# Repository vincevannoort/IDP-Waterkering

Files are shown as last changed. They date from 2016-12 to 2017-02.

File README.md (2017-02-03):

# IDP-Waterkering
De applicatie voor de IDP Waterkering levert een Proof of Concept voor een waterkering op schaal. De waterkering meet door middel van een ultrasonische sensor de waterstand. Indien het water te hoog staat worden waterkeringdeuren gesloten door stappenmotoren. Wanneer het water daarna weer op normaal niveau is, worden de waterkeringdeuren weer geopend. Door een failover systeem wordt gegarandeerd dat de waterkering altijd zal werken.

## Benodigdheden (hardware)
- HC-SR04 ultrasonische sensor - 1x
- 28byj-48 stappenmotor - 2x
- Raspberry Pi - 2x
- Jumper Wires (MM, MF, FF)
- Resistors (330ohm & 470ohm)
- Breadboard
- UTP netwerkkabel

## Installatie (software op beide Raspberry Pi's)
1. **Configureer Raspberry Pi's**  
   Formateer beide SD-cards via Win32DiskImager. Installeer Raspbian met behulp van een iso bestand. Verdere instructies te lezen op: [Raspbian install](https://www.raspberrypi.org/documentation/installation/installing-images/)
   
2. **Configureer verbinding Raspberry Pi's met sensoren en motoren**  
   Om de Raspberry Pi's met de sensors en motoren te verbinden in een schema gemaakt in Fritzing. Met de benodigdheden kun je de sensors en motoren aan het breadboard koppelen en het breadboard aan de twee Raspberry Pi's. [Fritzing instructie](http://i.imgur.com/pFn06OUg.png)

3. **Configureer netwerk**  
   Om de Raspberry Pi's met elkaar verbinding te kunnen laten maken, moet ervoor worden gezorgt dat de Raspberry Pi's een statisch IP hebben. Hiervoor moeten op beide Raspberry Pi's het netwerk interface bestand worden aangepast.  

   Raspberry Pi 1
   ```
   sudo nano /etc/network/interfaces
   ```
   ```
   auto eth0
   iface eth0 inet static
   address 192.137.0.1
   netmask 255.255.255.0
   ```
   Sla op met `ctrl+o`, `enter` gevolgd door `ctrl+x`  

   Raspberry Pi 2
   ```
   sudo nano /etc/network/interfaces
   ```
   ```
   auto eth0
   iface eth0 inet static
   address 192.137.0.2
   netmask 255.255.255.0
   ```
   Sla op met `ctrl+o`, `enter` gevolgd door `ctrl+x`
   Hierna kun je de verbinding testen door op Raspberry Pi 1 te pingen door ```ping 192.168.137.2``` in te voeren en vanaf Raspberry Pi 2 te pingen door ```ping 192.168.137.1``` in te voeren.

4. **Configureer SSH op beide Raspberry Pi's**  
   Om de applicatie verbinding te laten maken met de Raspberry Pi's wordt een SSH verbinding gebruikt. Deze moet op beide Raspberry Pi's worden ingesteld. Voer op beide Raspberry Pi's het onderstaande commando in.
   ```
   sudo ssh-keygen
   ```
   ```
   sudo raspi-config
   ```  
   Raspberry Pi 1
   ```
   ssh-copy-id -i ~/.ssh/id_rsa.pub 192.137.0.2
   ```  
   Raspberry Pi 2
   ```
   ssh-copy-id -i ~/.ssh/id_rsa.pub 192.137.0.1
   ```  
   Hierna kun je de verbinding testen door op Raspberry Pi 1 het commando ```ssh 192.137.0.2``` in te voeren en vanaf Raspberry Pi 2 het commando ```ssh 192.137.0.1``` in te voeren.

5. **Installeer Django en Django Channels**  
   Raspbian komt geisntalleerd met Python3 en de package manager pip. Door middel van pip kun je de juiste packages installeren die ervoor zorgen dat de webserver kan draaien.
   ```
   sudo pip3 install Django
   ```
   ```
   sudo pip3 install -U channels
   ```

6. **Download applicatie naar beide Raspberry Pi's**  
   Om alle bestanden op de Raspberry Pi's te krijgen, kan de repository met git worden gekopieerd.
   ```
   git clone 'https://github.com/vincevannoort/IDP-Waterkering.git'
   ```

7. **Applicatie starten op beide Raspberry Pi's**  
   Op beide Raspberry Pi's moet de applicatie draaien. Op de eerste moet de Django server draaien, en op de tweede het failover script.  

   Raspberry Pi 1
   ```
   cd IDP-Waterkering/applicatie
   ```
   ```
   sudo python3 manage.py runserver
   ```  

   Raspberry Pi 2
   ```
   cd IDP-Waterkering/redudantie
   ```
   ```
   sudo python3 rpi2-check-last-db-update.py
   ```

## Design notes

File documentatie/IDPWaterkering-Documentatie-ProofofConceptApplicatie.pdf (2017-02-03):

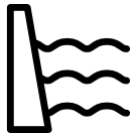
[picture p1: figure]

# Documentatie -Proof of Concept & Applicatie

IDP Waterkering

Gemaakt door:
Bart Hiemstra
Sijmen Jaarsma
Vince van Noort

IDP project 2016 - Sijmens Angels | Team 4 - V1B

### Inhoudsopgave

Documentatie -
Proof of Concept & Applicatie | 1
Inhoudsopgave | 2
Proof of Concept | 3
Functioneel Ontwerp | 4
Technisch Ontwerp | 6
Sensor | 6
Motoren | 6
Applicatie | 6
Websockets | 7
Programmeertaal | 7
Threads | 7
Failover | 7
Fritzing model | 8
Algemene werking | 9
Motor thread | 9
Sensor thread | 10
Testen van het systeem | 11
Doel | 11
Meten of de ultrasone sensor correct werkt | 11
Controleren of de poort opent/sluit op basis van de waterstand | 11
Testen of het failover systeem correct werkt | 12
Testen van de werking van de motoren | 12
Bronvermelding | 12

# Proof of Concept

Het Proof of Concept van de waterkering meet door middel van een ultrasonische sensor de waterstand. Indien het water te hoog staat worden sluisdeuren gesloten. Wanneer het water daarna weer op normaal niveau is, worden de sluisdeuren weer geopend. Door een failover systeem wordt gegarandeerd dat de waterkering altijd zal werken.

In het Proof of Concept zijn de onderstaande onderdelen gebruikt:

Hardware:
- HC-SR04 ultrasonische sensor - 1x
- 28byj-48 stappenmotor - 2x
- Raspberry Pi - 2x
- Jumper Wires (MM, MF, FF)
- Resistors (330ohm & 470ohm)
- Breadboard
- UTP netwerkkabel

Software:
- Django
- Django Channels
- Vue.js & Chart.js

### Functioneel Ontwerp

In het Plan van Aanpak is er beschreven wat de applicatie moet kunnen. De beschrijving die wij hebben gegeven luidt:

“Aan het einde van het project, op 3 februari 2017, wil ons team een prototype opleveren dat de maeslantkering nabootst. Dit prototype moet kunnen meten hoe hoog het water staat, de gemeten data opslaan en reageren op de stand van het water. De documentatie die wordt geschreven bij het prototype is duidelijk voor een student HBO-ICT eerstejaars aan de Hogeschool Utrecht. Het schaalmodel zal op zijn minst sensoren voor het meten van de waterstand bevatten, met daarnaast een sluisdeur die bediend wordt door twee stappenmotoren. Indien haalbaar willen we dit systeem werkzaam maken in een bak met water. Aan het einde van het project zullen wij een posterpresentatie houden die voldoet aan de eisen van het iPass project.”

Wat moet de het proof of concept concreet kunnen?

1. De applicatie moet kunnen draaien op een Raspberry Pi 3 Model B+
De Raspberry Pi 3 Model B+ is een minicomputer, ontworpen om applicaties te draaien. Ons team wil graag een Python programma laten draaien op zo’n minicomputer. Hiervoor moeten we rekening houden met wat de Raspberry Pi qua computerkracht aankan.
2. De waterstand moet per seconde kunnen worden gemeten door een ultrasonische sensor
De Raspberry Pi moet een ultrasonische sensor kunnen aansturen om de waterstand te meten. Een ultrasonische sensor is een sensor die een geluidsgolf afschiet met een erg hoge frequentie (onhoorbaar voor mensen). Deze geluidsgolf weerkaatst op een object. De tijd die de geluidsgolf erover doet om terug te komen naar de sensor, kan worden omgerekend naar een afstand op basis van de snelheid van geluid (343 meter per seconde).
3. De waterstanden moeten worden opgeslagen in een SQLite database
De gemeten afstand moet kunnen worden opgeslagen. Dit willen wij bereiken door dit in een SQLite database te doen. Een SQLite database is een enkel bestand die fungeert als database. In deze database kun je makkelijk data ophalen en opslaan.
4. De twee motoren moeten op basis van de gemeten waterstand worden aangestuurd
De motoren moeten worden aangestuurd door de applicatie op basis van de laatste paar metingen. Wanneer de gemeten waterstand over een langere tijd een ingestelde grens overschrijdt, zal de applicatie de motoren moeten aansturen om open of dicht te gaan.

### 5. De twee motoren moeten deuren kunnen dragen en een nauwkeurige aantal

graden kunnen draaien
De door de Raspberry Pi gestuurde motoren moeten een nauwkeurig aantal graden kunnen draaien terwijl deze de deuren van de waterkering draagt. Het aantal nauwkeurige graden moet kunnen worden beheerd in de applicatie.
6. Meldingen van het aansturen van de deuren moeten worden opgeslagen in een database
De meldingen die worden gegeven door de applicatie wanneer de deuren worden aangestuurd, moeten kunnen worden opgeslagen in een database (hiervoor benoemd).
7. De gemeten waterstanden en meldingen moeten in een webapplicatie worden getoond, hierin moet je een grafiek kunnen zien waarin je de waterstand van afgelopen minuut kunt bekijken
De waterstanden moeten worden weergegeven in een grafiek via de webapplicatie. Een webapplicatie is een applicatie die je via een browser kunt bekijken en hiermee interacteren. De grafiek biedt de optie om de geschiedenis van de waterstand te kunnen zien.
8. De sensoren en motoren moeten kunnen worden aangestuurd door een Raspberry Pi en indien deze uitvalt door een backup Raspberry Pi (ook wel Failover genoemd)
De waterkering moet met een failover systeem kunnen draaien. Dat betekent dat wanneer de Raspberry Pi (die de sensoren en motoren aanstuurt) uitvalt, een andere Raspberry Pi dit kan overnemen. Dit zorgt ervoor dat wanneer er geen stroom meer is of de applicatie crasht, het proces niet komt stil te staan.

### Technisch Ontwerp

In de onderstaande afbeelding is een representatie van het technisch ontwerp te zien, waarin de vereiste onderdelen zijn verwerkt. Hierin zijn de sluisdeuren weggelaten om alleen op het technisch gedeelte in te gaan.

### Sensor

De HC-SR04 ultrasonische sensor wordt gebruikt in het PoC. Er is voor deze sensor gekozen omdat het een goedkope maar zeer nauwkeurige sensor is. De sensor werkt op basis van geluid, zoals de naam al omschrijft. De sensor
kan op een afstand van 2 - 500 cm op 0.3cm nauwkeurig
meten, na deze afstand werkt de sensor niet meer naar
behoren. De sensor zal de afstand meten door de ultrasonische golf op het water te weerkaatsen en deze terug te ontvangen in de sensor. De sensor heeft vier pinnen waaronder: stroom, trigger, echo en aarde. Op bladzijde [BLADZIJDE] is gedocumenteerd hoe de ultrasonische sensor in het PoC is verwerkt.

Verantwoording: nauwkeurig en goedkoop

### Motoren

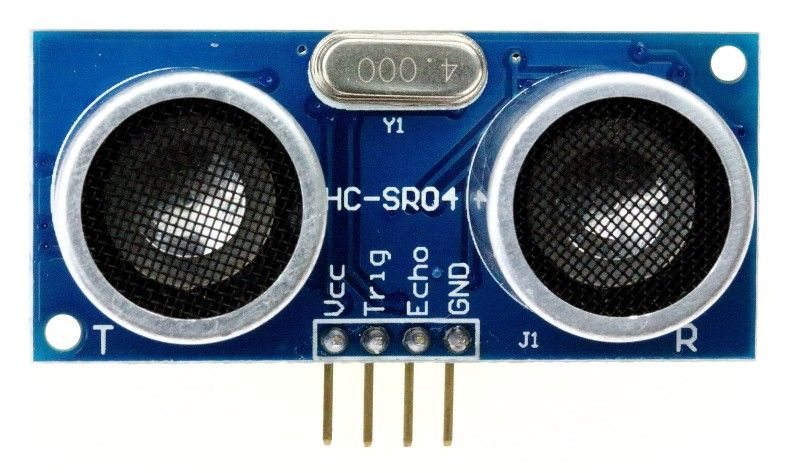
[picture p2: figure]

De 28byj-48 stappenmotor wordt gebruikt om de sluisdeuren aan te sturen. Deze stappenmotoren zijn gekozen omdat je ze aan kunt sturen
in een aantal graden en omdat ze heel goedkoop
beschikbaar zijn. Wanneer je een 28byj-48 stappenmotor
online bestelt, krijg je een motordriver bord erbij. De motoren werken door het aanzetten van verschillende magnetische velden. Door dit snel achter elkaar te doen gaat de motor draaien. Op bladzijde [BLADZIJDE] is gedocumenteerd hoe de stappenmotoren in het PoC zijn verwerkt.

Verantwoording: aantal graden aanstuurbaar en goedkoop

### Applicatie

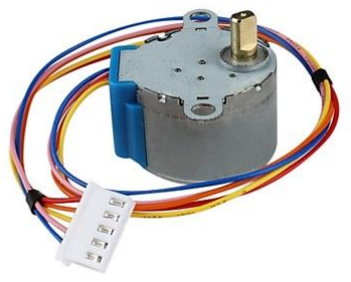
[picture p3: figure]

Om de applicatie is gekozen voor het Python Framework Django. De keuze voor Django is gebaseerd op dat Django betrouwbaar is en het toelaat om een applicatie snel te programmeren. Pinterest & Disqus zijn goede voorbeelden voor de betrouwbaarheid van Django, applicaties die dagelijks door
miljoenen mensen worden gebruikt.

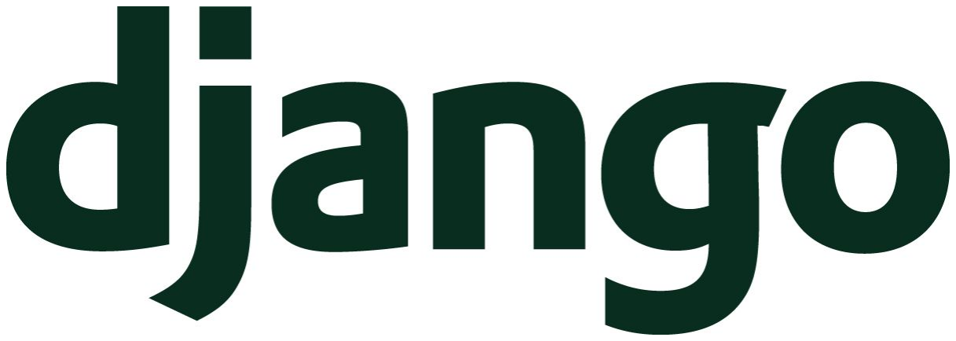
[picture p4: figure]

Verantwoording: betrouwbaar

### Websockets

Om vanaf meerdere browsers de webapplicatie synchroon te kunnen bekijken hebben we gekozen voor Django Channels. Een implementatie van websockets in Django. De websockets zorgen ervoor dat elke openstaande browser dezelfde updates door krijgt van de server. Zo zouden er meerdere schermen in een gebouw kunnen staan die de waterstanden door krijgen.

Verantwoording: synchroon monitoring en dichte integratie met Django

### Programmeertaal

Om de applicatie te programmeren hebben we samen met het framework Django gekozen voor Python. We hebben deze keuze gemaakt omdat Django is gebouwd op Python en om deze reden is de applicatie relatief erg snel in elkaar te zetten. Python is een programmeertaal die makkelijk te begrijpen is maar weinig grenzen heeft naast snelheid vergeleken met talen als C/C# en Java.

Verantwoording: prototype snel op te stellen

### Threads

We hebben er voor gekozen om met threads te werken voor de Applicatie. De reden hiervoor is dat we kunnen garanderen dat een lopende functie de andere functie niet blokkeert. In de applicatie zijn er naast de standaard Django threads, 2 threads die constant zichzelf herhalen. De implementatie van deze threads staat verderop in dit document beschreven.

Verantwoording: parallelle processen

### Failover

Voor de failover hebben we gekozen om twee Raspberry Pi’s met een ethernet kabel met elkaar te verbinden. De verbinding gaat via een veilige SSH verbinding met encryptie. Er zijn 2 verschillende type Raspberry Pi’s. De hoofd Raspberry Pi, en de failover Raspberry Pi. De hoofd Raspberry Pi kopieert elke 20 seconden de geupdate SQLite database file naar de Failover Raspberry Pi. De failover Raspberry Pi controleert elke 20 seconden of het databasebestand (dat vanaf de hoofd Raspberry Pi gekopieerd zou moeten zijn), niet ouder is dan 60 seconden. Indien het de hoofd Raspberry Pi, 3 keer niet is gelukt om het databasebestand te kopiëren, zal het databasebestand op de failover Raspberry Pi ouder zijn dan 60 seconden en zal de failover Raspberry Pi zijn eigen Django applicatie starten.

Kort uitgelegd:
1. De hoofd Raspberry Pi stuurt elke 20 seconden de meest recente database file naar de failover Raspberry Pi
2. De failover Raspberry Pi kijkt elke 20 seconden of het databasebestand (op het eigen apparaat) niet ouder is dan 60 seconden (de hoofd Raspberry kan er 3 keer niet in slagen om het bestand te kopiëren). Wanneer dit het geval is zal deze zelf de Applicatie starten.

Verantwoording: betrouwbaarheid en synchrone database

### Fritzing model

Voor het aansluiten van de 2 Raspberry Pi’s op de ultrasonische sensor en de stappenmotoren is het onderstaande technisch model te volgen.

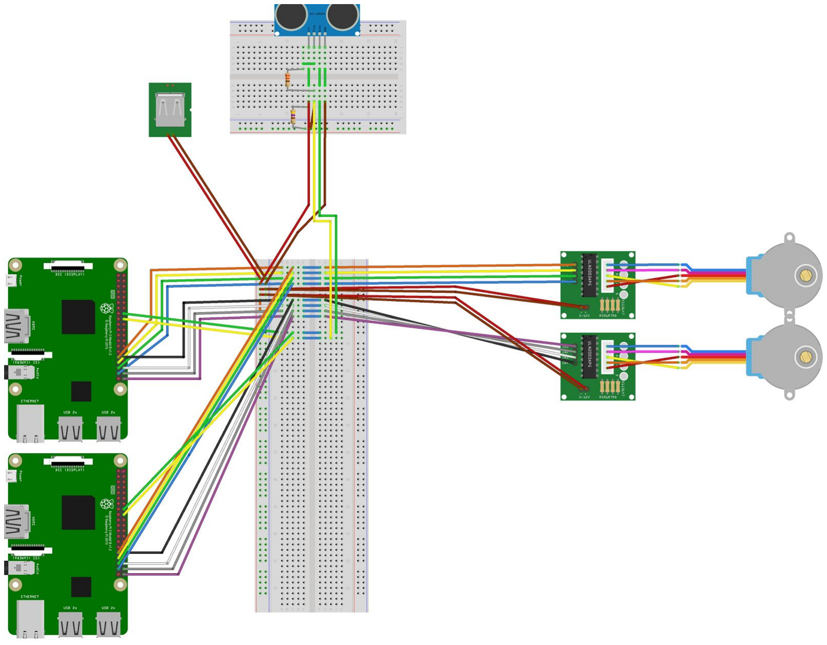
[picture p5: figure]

### Algemene werking

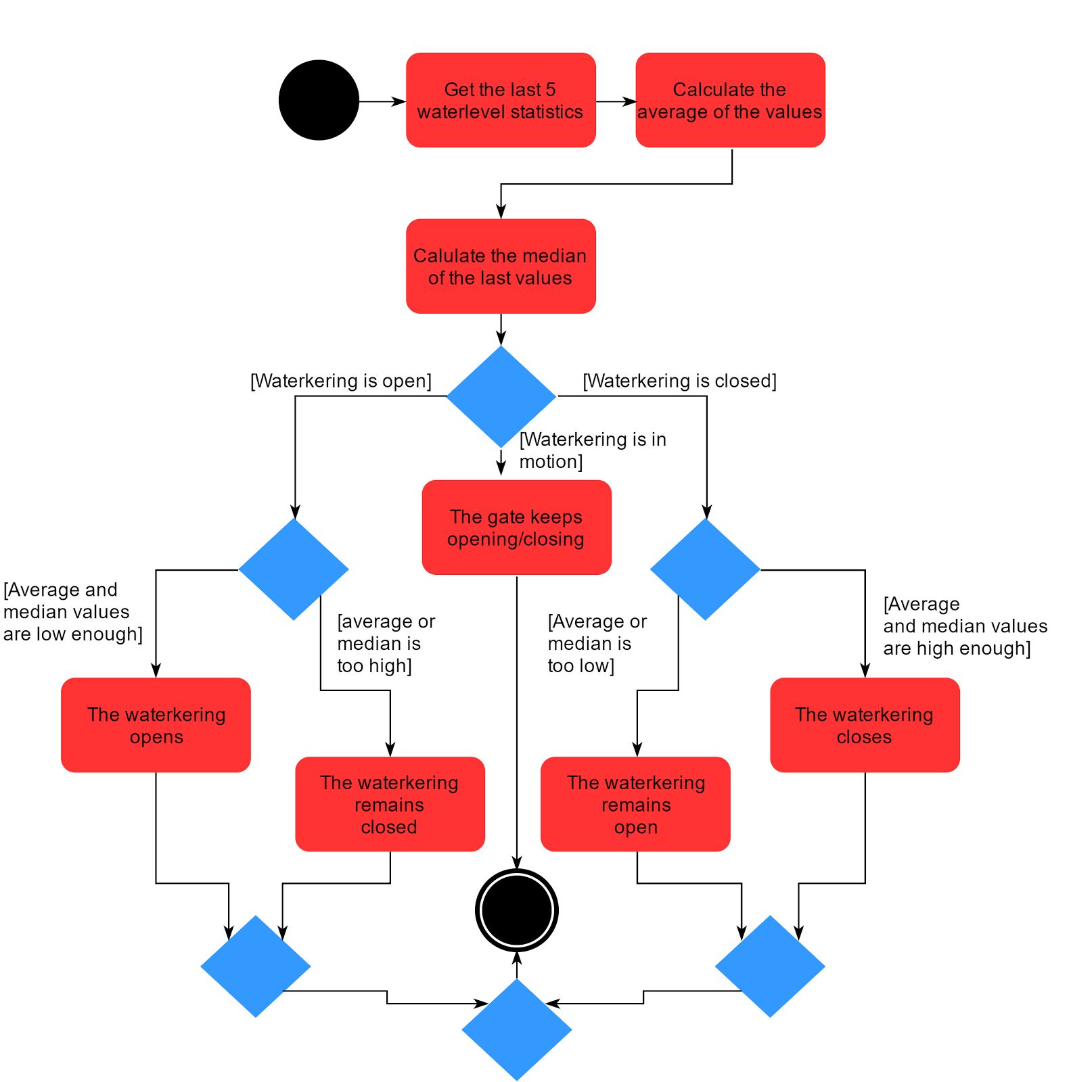
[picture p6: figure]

### Motor thread

Algemene werking applicatie:
1. De controller haalt de laatste 5 waterstanden op uit de database.
2. Van deze 5 waarden wordt het gemiddelde en de mediaan(de mediaan is de middelste waarde uit een gesorteerde lijst(bijvoorbeeld in [1; 4; 5 ] is 4 de mediaan)) berekend.
3. De waterkering controleert of de poort open, dicht of in beweging is:
a. als de poort open is wordt gecontroleerd of de poort dicht moet. Dit wordt gedaan door te checken of het gemiddelde en de mediaan hoger zijn dan de vastgestelde maximale waterhoogte.

b. als de poort dicht is is wordt gecontroleerd of de poort open moet. Dit wordt gedaan door te checken of het gemiddelde en de mediaan lager zijn dan de vastgestelde maximale acceptabele waterhoogte.
c. als de waterkering in beweging is veranderd er niks, de waterkering blijft open of dicht gaan.

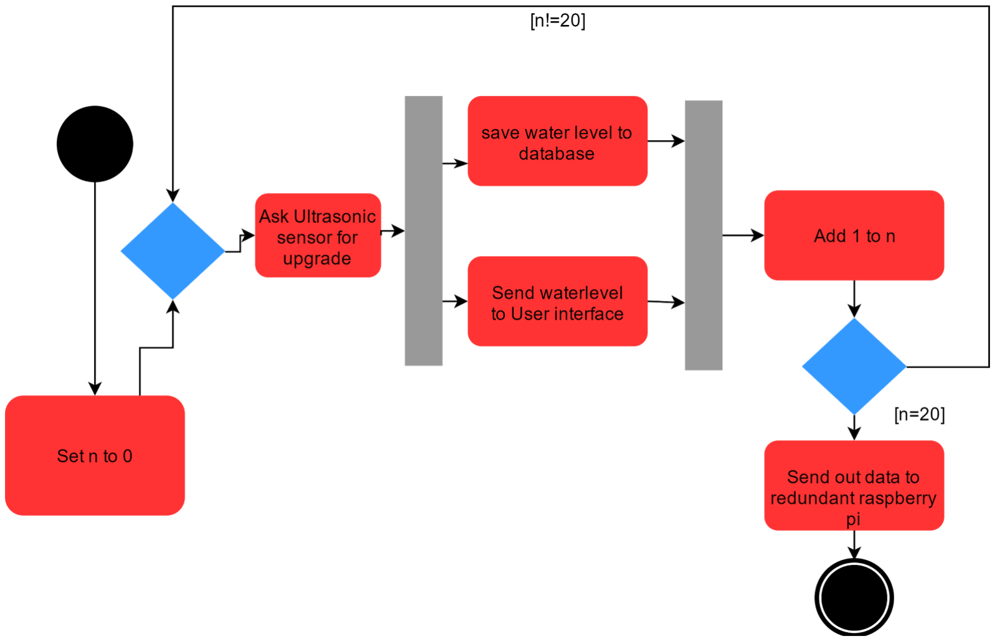
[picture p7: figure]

### Sensor thread

1. Tel 20 bij n op;
2. De ultrasone sensor krijgt de opdracht een mee om een nieuwe waarde op te meten;
3. voert de volgende 4 stappen 20 keer terug;
4. de ultrasone sensor geeft de waarden terug;
5. De thread slaat het opgehaalde waarde en de huidige tijd op in de django database;
6. De thread geeft de waterdata door aan de User Interface die dit weergeeft in zijn visuals;
7. tel een bij n op;
8. Update de database van de redundante raspberry pi.

# Testen van het systeem

### Doel

Het maken van een proof of concept waterkering die de waterstand meet en aan de hand van de binnengehaalde waarden bepaalt of de poort moet openen of sluiten. Verder moeten er een aantal tests uitgevoerd worden om te controleren of alle aspecten van het systeem goed werken.

### Te testen onderdelen

Hieronder staan de testmethoden uitgewerkt met daarbij het resultaat van elke test.

### Meten of de ultrasone sensor correct werkt

Benodigdheden
- Verstelbaar waterreservoir
- Ultrasone sensor
- Liniaal

Testmethode
De afstand tussen de ultrasone sensor en het wateroppervlak wordt gemeten met behulp van een liniaal. Vervolgens wordt de afstand afgelezen die de sensor geeft. Als de waardes overeenkomen dan is de ultrasone sensor correct ingesteld.

Testresultaat
De waardes van de ultrasone sensor komen overeen met wat de liniaal aangeeft.

### Controleren of de poort opent/sluit op basis van de waterstand

Benodigdheden
- Geteste ultrasone sensor
- Gemotoriseerde poorten
- Verstelbaar waterreservoir

Testmethode
Het systeem wordt aangezet, waarna een waterreservoir wordt gevuld en vervolgens weer geleegd. Daarbij wordt gecontroleerd of de poorten correct sluiten wanneer het reservoir te vol zit, en weer openen wanneer het reservoir te leeg is. Deze test wordt 4 keer uitgevoerd om er zeker van te zijn dat alles werkt.

Testresultaat
De poort opent en sluit op het goede moment.

### Testen of het failover systeem correct werkt

Benodigdheden
- Een volledig redundant systeem met 2 Raspberry Pi's.

Testmethode
De Raspberry Pi die verantwoordelijk is voor het aansturen van de sluisdeuren wordt opzettelijk gestopt. Vervolgens wordt gekeken of de tweede Raspberry Pi het werk van de eerste overneemt. Deze test herhalen we 4 keer. Als het failover systeem in alle gevallen werkt wordt het als correct werkend beschouwd.

Testresultaat
Het failover systeem werkt correct.

### Testen van de werking van de motoren

Benodigdheden
- Alle andere tests succesvol uitgevoerd
- Het geheel opgestelde systeem.

Testmethode
De test knoppen ‘Open gate’ en ‘Close gate’ die zich in de webapplicatie bevinden worden kort na elkaar ingedrukt. Er wordt gekeken of de poort goed opent en weer sluit. Als dat zo is wordt de test als succesvol beschouwd.

Testresultaat
De poorten openen en sluiten correct na het drukken op de knoppen. De motoren werken dus zoals gewenst.

# Bronvermelding

1. Rijkswaterstaat. Geraadpleegd van: https://www.rijkswaterstaat.nl/water/waterbeheer/bescherming-tegen-het-water/waterkeringen/index.aspx (https://www.rijkswaterstaat.nl/water/waterbeheer/bescherming-tegen-het-water/waterkeringen/index.aspx)
2. Tutorials point. (z.j.). Python Multithreaded Programming. Geraadpleegd van: https://www.tutorialspoint.com/python/python_multithreading.htm
3. Python - Tutorial. (z.j.). Geraadpleegd van https://www.tutorialspoint.com/python/

4. Barnett, J. (2014, 11 april). Controlling DC Motors Using Python With a Raspberry Pi. Geraadpleegd van
https://business.tutsplus.com/tutorials/controlling-dc-motors-using-python-with-a-raspberr y-pi--cms-20051 (https://business.tutsplus.com/tutorials/controlling-dc-motors-using-python-with-a-raspberry-pi--cms-20051)
5. Raspberry, M. (2012, 13 augustus). Reading Analogue Sensors With One GPIO Pin. Geraadpleegd van
http://www.raspberrypi-spy.co.uk/2012/08/reading-analogue-sensors-with-one-gpio-pin/
6. Raspberry, M. (2012, 13 augustus). Ultrasonic distance measurement using python part
2. Geraadpleegd van
http://www.raspberrypi-spy.co.uk/2013/01/ultrasonic-distance-measurement-using-python-part-2/ (http://www.raspberrypi-spy.co.uk/2013/01/ultrasonic-distance-measurement-using-python-part-2/)
7. Wiles, F., Procida, D., Bennett, J., Conley, R., Love, K., & Alger, K. W. (z.j.). Django. Geraadpleegd van https://www.djangoproject.com/
8. Stateham, B. (2014, 11 april). 28BYJ-48 Stepper Motor and ULN2003 Driver Intro. Geraadpleegd van https://www.youtube.com/watch?v=B86nqDRskVU

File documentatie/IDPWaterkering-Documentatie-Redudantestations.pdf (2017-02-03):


# Documentatie - Redundante stations

IDP Waterkering

Gemaakt door:
Sijmen Jaarsma
Jeroen van der Burgt

IDP project 2016 - Sijmens Angels | Team 4 - V1B

## Inhoudsopgave

Documentatie - Redundante stations | 1
Inhoudsopgave | 2
Inleiding | 3
Benodigdheden | 3
Hardware | 3
Raspberry Pi 3 Model B - 2x | 3
UTP netwerkkabel | 3
Software | 4
Raspbian | 4
Django | 4
Nano | 4
Python libraries | 4
os | 4
time | 4
import subprocess | 4
Installatie stapsgewijs | 5
Werking | 8
Bronvermelding | 9

## Inleiding

Dit is de documentatie over de failover van de proof of concept waterkering. Als de raspberry pi die de waterkering runt crashed kan een tweede raspberry pi de draad oppakken zonder veel data te verliezen. Op deze manier voorkom je ook dat de waterkering niet werkt op het moment waarop je waterkering in actie moet komen.

## Benodigdheden

hieronder volgt een lijst van keuzes die we gemaakt hebben over het gebruik van hardware en software communicatie bij het opzetten van een redundant systeem. Erbij staat vermeld waarom we deze systemen gebruiken.

### Hardware

Alle fysieke objecten die gebruikt zijn voor het maken van het systeem.

Raspberry Pi 3 Model B - 2x

We gebruiken twee Raspberry Pi’s waarvan we van eerste (de main Raspberry Pi) gebruiken om de waterkering aan te sturen. De bedoeling is dat de tweede (backup) Pi het werk van hem overneemt, als de eerste Raspberry Pi uitvalt.

Raspberry Pi’s zijn goedkoper dan de meeste minicomputers op de markt. Ze zijn zeer makkelijk in gebruik, vanwege het toestaan van de programmeertaal Python als basistaal voor de hardware, waardoor het opstellen van een proof of concept goed mogelijk is.

UTP netwerkkabel

Voor de verbinding tussen de twee Raspberry Pi’s gebruiken wij een UTP netwerkkabel. Dit is alleen zo in het proof of concept, voor een officiële implementatie zouden we meerdere UTP kabels gebruiken om te voorkomen dat communicatie uitvalt als een van de UTP kabels breek

UTP kabels zijn beter om te gebruiken dan een lokale router met een wireless netwerk, ze zijn snel, betrouwbaar en relatief goedkoop. Glasvezel zou ook een goede optie zijn, maar dat is moeilijker om aan te leggen

### Software

Een lijst van software toepassingen die we gebruikt hebben:

Raspbian

Het standaard besturingssysteem op een Raspberry Pi, perfect om onze python code te draaien. Linux staat al een aantal jaren bekend als het besturingssysteem dat het meest continue kan draaien zonder dat er fouten ontstaan in de software.

We hebben voor Raspbian gekozen in plaats van Noobs, omdat er bredere ondersteuning bestaat voor Raspbian (het lijkt meer op debian, een operating system dat op veel meer systemen wordt gebruikt dan alleen Raspberry Pi’s).

Django

De keuze voor Django is niet direct van relevantie voor het redundant systeem. We hebben ervoor gekozen omdat django geschikt is om een goed werkende visuele layout te maken. We hebben uitgezocht of Django goed kon werken met redundantie en het leverde geen problemen op.

Nano

Een standaard applicatie van linux die perfect is voor het aanmaken en bewerken van Python bestanden. We kunnen deze applicatie ook gebruiken om snelle aanpassingen aan de Django code aan te brengen.

### Python libraries

Er zijn een aantal libraries (extensions) voor Python die we gebruikten om redundantie mogelijk te maken.

os

Deze import zorgt ervoor dat de Python code direct commando’s aan het Raspbian operating system kan geven. Zo laten we het operating system de stappen maken die we nodig hebben om redundantie te laten optreden.

time

Zorgt ervoor dat je een proces voor een bepaalde tijd kan laten rusten waardoor je Raspberry Pi niet overbelast raakt. Je kunt hiermee ook achter de leeftijden van aanpassingen komen.

import subprocess

Zorgt ervoor dat een Python applicatie een andere applicatie kan opstarten. Op deze manier kan de backup Raspberry het werk van de main Raspberry opstarten in zijn eigen code.

## Installatie stapsgewijs

1. Als eerste beginnen we met Raspbian, deze moet geconfigureerd worden via een SD-Card. Deze kan geformatteerd worden via Win32DiskImager. Dat is een programma dat automatisch de SD-Card formatteert en Raspbian installeert. Het bestand dat je kan downloaden van de website is een .iso bestand. Met behulp van Win32DiskImager kan je de SD-Card selecteren en deze laten formatteren en daarna de juiste bestanden erop laten zetten.
2. Daarna moet er, voor het Technische Informatica gedeelte, Django en Django channels geïnstalleerd worden. Dit hebben we gedaan door middel van pip. Pip is een package manager, voor softwarepakketten voor Python, die we met vorige projecten ook nodig hebben gehad. Het voordeel van pip is dat meerdere bestanden tegelijkertijd kan installeren. Op het moment dat je Django en Django channels wil installeren gebruik je de volgende commando’s:

sudo pip3 install Django

sudo pip3 install -U channels

3. Op het moment dat Django en Channels geïnstalleerd is gaan we het IP aanpassen van de Pi. Dit doen we zodat hij later gemakkelijk verbinding kan maken met ssh (Secure Shell). Navigeer naar de interfaces tab met:

sudo nano /etc/network/interfaces

Pas daarna de standaardinstelling van Eth0 aan, zodat deze automatisch verbinding probeert te maken met een pi op een static IP adres.

Configuratie Raspberry Pi 1 (Main Raspberry Pi)
auto eth0
iface eth0 inet static
address 192.137.0.1
netmask 255.255.255.0

Configuratie Raspberry Pi 2 (Backup Raspberry Pi) auto eth0
iface eth0 inet static
address 192.137.0.2
netmask 255.255.255.0

Sla nu op met ctrl+o, dan de enter toets en daarna ctrl+x.

De netwerkinstellingen zijn hiermee voltooid.

4. Op het moment dat beide netwerkverbindingen ingesteld staan als bovenstaande, wordt het u aangeraden om de Raspberry Pi opnieuw te laten opstarten. Dit wordt gedaan met het volgende commando:

sudo reboot

Als de instellingen nu juist zijn ingesteld dan kan er een ping plaatsvinden tussen de beide Raspberry Pi’s. Dit doen we om te bekijken of er verbinding kan plaatsvinden tussen beide Raspberry Pi’s.

Raspberry Pi 1 (Main Raspberry Pi)
ping 192.168.137.2

Raspberry Pi 2 (Backup Raspberry Pi)
ping 192.168.137.1

Als er een verbinding gemaakt wordt dan ziet dit er ongeveer zo uit:

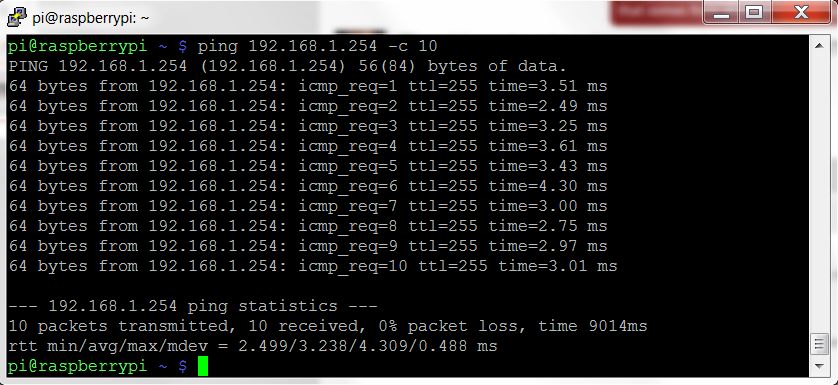
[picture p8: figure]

Op dat moment kan de volgende stap gemaakt worden.
5. SSH instellen voor de raspberry pi connectie. Er zal op dit moment de mogelijkheid zijn om ssh in te stellen voor de Raspberry Pi.Dit is nodig, zodat het backup systeem feilloos gaat werken. Op dit moment zijn er nog geen keys gegenereerd en daarom gaan we dit als eerst doen:

sudo ssh-keygen

Daarna kunnen de standaardinstellingen hetzelfde blijven, druk op enter, totdat de keygen aangemaakt is. Op dit moment is er een ssh key beschikbaar en opgeslagen op de Raspberry Pi. Nu is het de zaak om dit ook op de andere Raspberry Pi aan te maken. Mocht het zo zijn dat ssh uitgeschakeld staat op uw Raspberry Pi, dan kunt u deze inschakelen op deze manier:

sudo raspi-config

Daarna kan er via Advanced Options, ssh aangezet worden.

6. Nu gaan we de virtuele handdruk maken door het wachtwoord van de andere Raspberry Pi in te vullen op de eerste Raspberry Pi. Dan kunnen met de eerste Raspberry Pi inloggen zonder een wachtwoord in te moeten vullen, omdat de key wordt opgeslagen in een database.

Configuratie Raspberry Pi 1 (Main Raspberry Pi)
ssh-copy-id -i ~/.ssh/id_rsa.pub 192.137.0.2

Configuratie Raspberry Pi 2 (Backup Raspberry Pi)
ssh-copy-id -i ~/.ssh/id_rsa.pub 192.137.0.1

Als dit is ingesteld kan er een altijd verbinding worden gemaakt met de andere Pi, zonder een wachtwoord in te moeten vullen. Dit kan je doen door middel van het volgende commando:

Op Raspberry Pi 1 (Main Raspberry Pi) voor het verbinding maken naar Raspberry Pi 2 (Backup Raspberry Pi).
ssh 192.137.0.2

Op Raspberry Pi 2 (Backup Raspberry Pi) voor het verbinding maken naar Raspberry Pi 1 (Main Raspberry Pi).

ssh 192.137.0.1

Na deze acties kan de code worden uitgevoerd op de Raspberry Pi.

## Werking

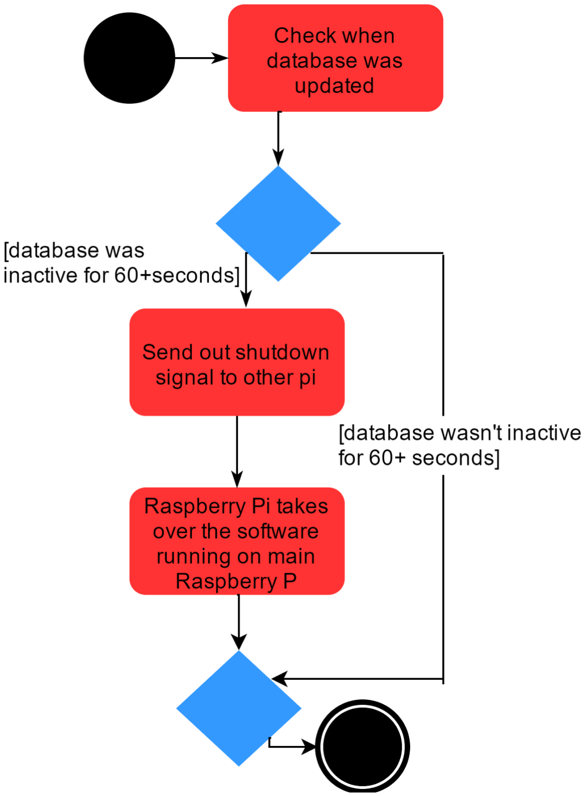
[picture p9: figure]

De failover werkt in een paar stappen:
1. Raspberry 1 voert zijn standaard metingen uit en slaat ze op in de database;
2. Elke 20 metingen worden de metingen verstuurd naar de backup raspberry om daar de database bij te werken;
3. Elke 20 seconden checkt de backup pi of deze updates heeft gekregen van het centrale systeem;
a. Als de laatste update meer dan 60 seconden geleden was dan geeft hij de eerste raspberry pi een shutdown commando
b. Als de laatste update minder dan 60 seconden geleden was dan herstart hij vanaf stap 1

# Bronvermelding

Natarajan, R. (2008, 20 november). 3 Steps to Perform SSH Login Without Password Using ssh-keygen & ssh-copy-id. Geraadpleegd van http://www.thegeekstuff.com/2008/11/3-steps-to-perform-ssh-login-without-password-using-s sh-keygen-ssh-copy-id (http://www.thegeekstuff.com/2008/11/3-steps-to-perform-ssh-login-without-password-using-ssh-keygen-ssh-copy-id)

Raspberrypi.org. (z.j.). 3 Steps to Perform SSH Login Without Password Using ssh-keygen & ssh-copy-id. Geraadpleegd op 20 januari, 2017, van https://www.raspberrypi.org/documentation/remote-access/ssh/scp.md

RPI ADMIN (2015, 19 mei). Django + Raspberry Pi Tutorial (PART I). Geraadpleegd van http://raspberrypituts.com/django-raspberry-pi-tutorial/

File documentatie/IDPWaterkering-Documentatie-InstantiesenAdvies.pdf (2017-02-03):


# Documentatie - Instanties en Advies

IDP Waterkering

Gemaakt door:
Jody Schuller
Jay Termaat

IDP project 2016 - Sijmens Angels | Team 4 - V1B

# Inhoudsopgave

Documentatie - Instanties en Advies | 1
Inhoudsopgave | 2
Documentatie - Instanties en Advies | 3
Werking van de waterkering | 3
Werking actuele bouwconstructie | 3
De verschillende waterkeringen in ons land | 3
Onderhoud | 4
Kleurcodes | 4
Betrokken instanties en verantwoordelijkheden | 5
Verantwoordelijkheden Rijkswaterstaat | 5
Software componenten | 5
Overige betrokkenen | 6
Modellen | 7
BPMN | 7
Use case | 7
Activity diagram | 10
Bronvermelding | 12

## Documentatie - Instanties en Advies

## Werking van de waterkering

Werking actuele bouwconstructie
Om de werking van de actuele waterkeringen te beschrijven gebruiken we er even één als voorbeeld. Dit doen we omdat ze allemaal volgens hetzelfde principe werken.
De Maeslantkering is een kering, gelegen in de Europort te Hoek van Holland, Rotterdam. Deze bestaat uit twee enorme deuren van 22 meter hoog en 210 meter breed. Deze deuren drijven op het water, en draaien naar elkaar toe bij de sluitingsprocedure. Dit sluiten wordt geheel automatisch gedaan en gebeurt wanneer het waterpeil meer dan 3 meter boven NAP (Normaal Amsterdams Peil) is voorspeld bij Rotterdam, en meer dan 2,9 meter boven NAP bij Dordrecht. Mocht er iets niet goed gaan, dan staat het operationeel team klaar. Dit team is speciaal gericht op deze werkzaamheden. Ze zijn ook buiten het stormseizoen actief met het bijhouden van hun kennis omtrent deze activiteiten. Vlak voor het begin van het stormseizoen wordt dit team getest bij een functioneringssluiting. Dit is een test voor de keringen en het operationeel team om te garanderen dat ze goed voorbereid het stormseizoen in gaan.

De verschillende waterkeringen in ons land
Om ons te beschermen tegen het water, heeft ons land ruim 3700 kilometer aan waterkeringen. Naast keringen, zoals duinen, zijn er bijna 1500 aangelegde waterkeringen. Hieronder staan de belangrijkste op een rijtje.

De Oosterscheldekering is de kroon van de deltawerken. Deze is 9 kilometer lang en hiervan is 3 kilometer compleet af te sluiten. De kering bestaat uit 65 pijlers van 18.000 ton en 62 schuiven die 42 meter lang en 6 tot 12 meter hoog zijn. Als de waterstand 3 meter boven NAP is, dan wordt de kering met één druk op de knop gesloten. Na ongeveer 74 minuten is de kering helemaal dicht. Wanneer deze compleet gesloten is zal deze de gebieden rondom de Oosterschelde beschermen.

De Hollandsche Ijsselkering heeft 4 torens van 45 meter hoog. Hiertussen hangen twee afzonderlijk beweegbare schuiven van 80 meter breed en 12 meter hoog. Deze wegen 480 ton. In de avond zijn de torens verlicht met een blauwe kleur en de trappen met een witte kleur. Op het moment van sluiting worden de kleuren rood. Dit zorgt voor een gelijke alarmering van het volk. Als er een verhoging van 2.25 meter boven NAP wordt verwacht dan moet minimaal 1 schijf dicht tot op de bodem van de rivier. Dit gebeurt gemiddeld 3 keer per jaar. De andere schijf is dan in geval van nood. Deze kering is bedoeld om het water van de maas tegen te houden en beschermt zo de mensen rondom de Hollandsche IJssel.

De Maeslantkering heeft 2 halvemaanvormige, holle deuren van 22 meter hoog en 210 meter breed. De bolscharnieren in de kering wegen 680 ton per stuk en hebben een diameter van 10 meter. Als een waterstand van 3 meter boven NAP in Rotterdam of 2,9 meter in Dordrecht wordt verwacht gaan de deuren volledig automatisch dicht. Hierdoor is de Maeslantkering in staat om een waterstand van 5 meter boven NAP tegen te houden. Sluiting is echter aan de langzame tijd, twee uur. De scheepvaart wordt automatisch gewaarschuwd. Sinds de bouw in 1997 is de kering 1 keer gesloten, in november 2007. Ook is pas geleden, januari 2017 bijna gesloten. Sinds de sluiting in 2007 vindt er jaarlijks één functioneringssluiting plaats.

De Hartelkering wordt samen met Maeslantkering de Europoortkering genoemd. De Hartelkering zelf heeft 4 torens met 2 ellipsvormige schijven ertussen hangen. De kleinste schijf is 49 meter en de grote is 98 meter. Ze hangen op een hoogte van 14 meter boven zeeniveau.

De Ramspolkering is een soort ballon op de bodem van de rivier. Bij een waterstand van 50 centimeter boven NAP wordt deze opgeblazen. Er wordt dan 3.500.000 liter lucht en 3.500.000 liter water in gepompt. Wanneer opgeblazen is de barrière 10 meter hoog en 80 meter lang op de eerste dinsdag van september vindt er een proefsluiting plaats.

Onderhoud
Het onderhoud van de waterkeringen wordt gedaan door Rijkswaterstaat. Zij zorgen ervoor dat de keringen gedurende een stormseizoen te allen tijde kan sluiten. Gedurende het hele jaar worden er testen, inspecties, en onderhoudswerkzaamheden uitgevoerd. Het grootste deel van het onderhoud vindt buiten het stormseizoen plaats (half april - eind september). Hieronder een beslissingsboom voor het bepalen van het onderhoud. Dit model geldt echter niet voor het dagelijkse onderhoud, zoals het onderhouden van de kunstwerken in het museum en het maaien van het gras. Deze twee onderhouden worden overigens gedaan door de afdeling District Hertogswetering en Raam.

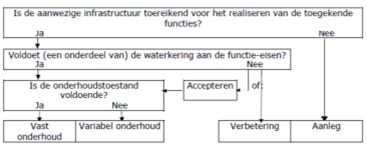
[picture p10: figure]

Kleurcodes
Als er op rivieren, meren en langs de kust zodanig hoog water verwacht wordt, dat de vastgestelde grenswaarden overschreden worden of als sprake kan zijn van hevige overlast door neerslag, wordt er volgens staticrecources.nl gebruik gemaakt van de volgende kleurcodes: Groen: Er is sprake van regulier dagelijks waterbeheer.
Geel: Enkele verhoogde waterstanden zorgen ervoor dat er standaard maatregelen worden genomen. Hierdoor worden scheepvaart en andere activiteiten op het water mogelijk beperkt. Geel komt over het algemeen meerdere keren per jaar voor.
Oranje: Bij deze kleur neemt hoogwater toe, hierdoor zullen er verdergaande maatregelen worden genomen. Activiteiten en gebruiksfuncties op het water worden op een verhoogd niveau beperkt. De kans is aanwezig dat er lichte schade aan de waterkeringen zal optreden. Bij oranje worden er vaak ook al voorbereidingen gepleegd voor de mogelijke code rood. Oranje komt gemiddeld vijf keer per jaar voor.
Rood: Rood is een ernstige en uitzonderlijke situatie in het watersysteem met als gevolg grootschalige noodmaatregelen. Deze zijn vaak al voorbereid en klaar om ingezet te worden. Burgers worden gewaarschuwd, en wanneer nodig zelfs geëvacueerd. De kans is groter dat er schade op zal treden bij de keringen. Bij rood kan de nationale veiligheid in het geding zijn. Kleurcode rood komt gemiddeld eens in de 20 tot 100 jaar voor.

## Betrokken instanties en verantwoordelijkheden

Hieronder de groepen die betrokken zijn bij het onderhoud van de Maeslantkering.

Verantwoordelijkheden Rijkswaterstaat
Binnen Rijkswaterstaat zijn er verschillende afdelingen verantwoordelijk voor het beheer en onderhoud. Volgens de site inspectiewaterkeringen.nl wordt het voornamelijk uitgevoerd door de afdeling Advies Waterbeheer. Daarnaast zijn er nog enkele afdelingen die zich hiermee bezighouden:
- Afdeling Integraal Beleid (landelijke en strategische ontwikkelingen);
- Ontwerp & Realisatie (inspectie en renovatie kunstwerken, opstellen maaibestek). Deze afdeling is dus meer bezig met het onderhouden van de onderdelen die weinig met de kering zelf te maken hebben;
- Planadvies en vergunningverlening;
- Handhaving (beveiliging etc.).

Software componenten
Bij elk van de waterkeringen ondervinden we 3 verschillende lagen van software. Dit zijn de Ringtoets, de HydraRing en het D-soil model. Elk model heeft een eigen faalmechanisme en deze faalmechanismen hebben als ondergrond het D-soil model. Het complete plaatje noemen we de ‘ringtoets (User interface)’. In de ringtoets wordt alles weergegeven aan de gebruiker. Alle berekeningen worden in een schema gezet en kunnen door het Operationeel Team (OT) bekeken worden. De HydraRing en de ringtoets werken samen als een goed geoliede machine. De HydraRing en de ringtoets zorgen beide voor wat uiteindelijk waargenomen kan worden door de het OT. Ondanks dat alle systemen op zichzelf lijken te werken is het tegenovergestelde waar. Alle systemen zijn afhankelijk van elkaar en ook afhankelijk van dezelfde faalsystemen. Hieronder de uitgebreide beschrijvingen van alle componenten:
1. Ringtoets, De user interface van deze WBI 2017 software is het meest tastbare van alle softwarecomponenten. Ringtoets wordt ook wel gezien als de gebruikersschil. Hiermee wordt toetsing uitgevoerd. Als gebruiker van de ‘ringtoets’ voer je een schematisering in. Hierna wordt de faalmechanisme model in werking gesteld en een analyse gemaakt van de risico’s. Het D-soil model speelt hier ook een belangrijke rol in. De letterlijke betekenis van ringtoets is ‘de hydraulische belastingen voor de standalone applicaties’.

2. Het belangrijkste onderdeel van de ringtoets is de HydraRing, dit is als het ware het rekenhart van de ringtoets. De HydraRing kan de overstromingskans en het dijktraject berekenen. Dit werkt doordat de HydraRing de sterkte van de waterkering door elk faalmechanisme haalt. Hierna wordt een zogeheten ‘weging’ uitgevoerd en wordt de uitslag hiervan in een zogeheten toetslaag verwerkt. In de HydraRing zijn alle faalmechanisme modules opnieuw geprogrammeerd, gedocumenteerd en getest. Hierdoor zijn de laatste onzekerheden teniet gedaan.
3. Het D-soil model is als het ware de fundering van verschillende faalmechanismen. Piping, Macrostabiliteit en zetting vloeistof hebben allemaal D-soil als fundering. Met D-Soil Model kunnen beheerders de globale stochastische ondergrond schematisatie omvormen tot schematisaties. Dit is een stuk makkelijker en betrouwbaarder af te lezen voor de gebruiker. Nadat materiaaleigenschappen zijn toegekend, worden deze schematisaties door de ringtoets gebruikt.

Overige betrokkenen
De Rijkswaterstaat beheert en onderhoudt eigenlijk vrijwel alles zelf, zo wordt op de website van de organisatie zelf aangegeven. Zoals eerder aangegeven wordt dit onderverdeeld onder verschillende afdelingen. Alleen de Hartelkering (onderdeel van de Europoortkering samen met de Maeslantkering) wordt niet door Rijkswaterstaat onderhouden. Het onderhoud van deze kering wordt namelijk uitbesteed aan een aannemer. Rijkswaterstaat wilt verder niet aangeven welke aannemer dit is.

## Modellen

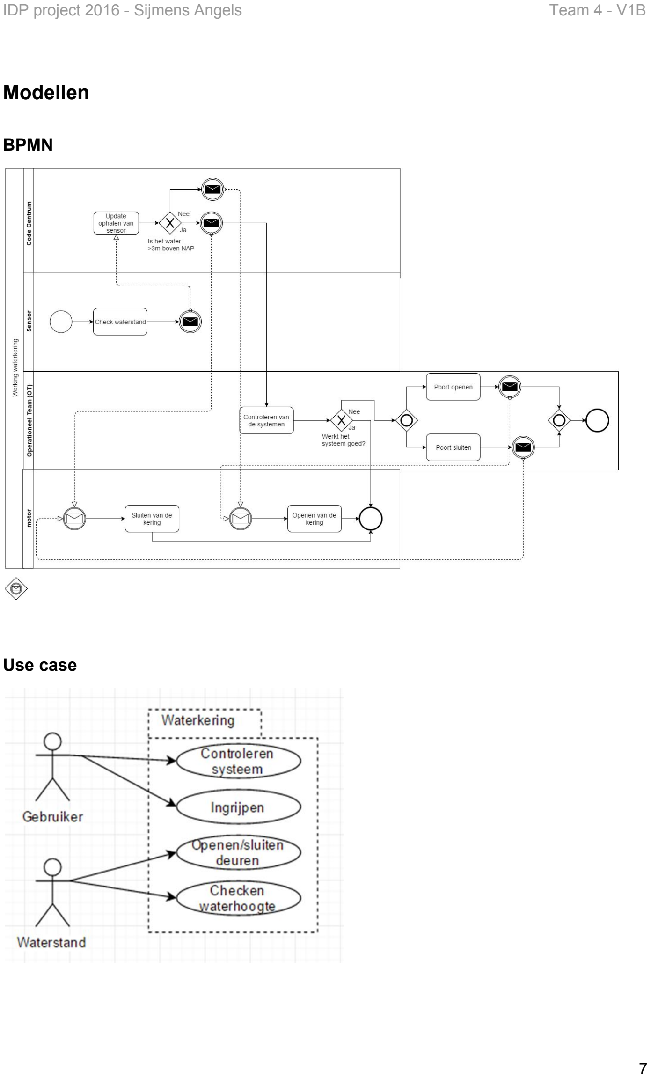
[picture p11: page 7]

BPMN

Use case

ID : | UC01-CS
Naam: | Controleren systeem
Actoren: | Gebruiker
Beschrijving: Het operationeel team (gebruiker) controleert blijft continu de systemen checken op fouten. Mochten er fouten gevonden worden, wat niet vaak gebeurt, wordt er direct ingegrepen.
Preconditie: -
Scenario:
1. Actor start systeem
2. Systeem geeft informatie
Postcondities: - | Het systeem is gecontroleerd
ID: | UC02-I
Naam: | Ingrijpen
Actoren: | Gebruiker
Beschrijving: Wanneer de waterstand te hoog is, worden de deuren gesloten. Er zijn echter
| uitzonderingen waarbij dit fout gaat. Het operationeel team (gebruiker) is er
| om bij deze situaties in te grijpen en het op te lossen. Voor deze situaties
| worden ze het hele jaar getraind.
Precondities: -

Scenario:
1. Actor start systeem
2. Systeem geeft informatie
2.1. Foutmelding
2.1.1. Operationeel team grijpt in
2.1.2. Naar stap 3
2.2. Proces verloopt goed
2.2.1. Naar stap 3
3. Beëindigen proces

Postconditions: - Er zitten geen fouten meer in het systeem;
- Het proces is beëindigd.

ID: | UC03-OS
Name: | Openen/sluiten deuren
Actoren: | Waterstand
Beschrijving: Wanneer de hoogte van het water 3 meter boven NAP in Rotterdam of 2.9 meter boven NAP in Dordrecht wordt verwacht, zullen de deuren sluiten. Wanneer dit niet meer nodig is, zullen de deuren ook weer open moeten. Dit gebeurd, mits er geen problemen zijn, geheel automatisch.
Precondities: -

Scenario:
1. Actor vraagt waterhoogte op.
2. Indien waterhoogte boven 3 meter boven NAP
2.1. Sluiten sluisdeuren.
2.2. Verder naar stap 4
3. Indien waterhoogte onder 3 meter boven NAP en sluisdeuren zijn dicht
3.1. Open sluisdeuren
3.2. Verder naar stap 4
4. Proces beëindigen

Postconditions: - Sluisdeuren zijn, indien nodig, gesloten dan wel geopend;
- Het proces is beëindigd.
ID: | UC04-CW
Naam: | Checken waterhoogte
Actor: | Waterstand
Beschrijving: Om te kunnen bepalen of de sluisdeuren gesloten moeten worden, geopend moeten worden, of natuurlijk geopend moeten blijven, moet het systeem de waterhoogte weten.

Scenario:
1. Actor vraagt waterhoogte op
2. Systeem controleert waterhoogte bij Rotterdam en Dordrecht
3. Systeem verstrekt gegevens
4. Proces beëindigen

Postconditions: - Actor heeft gegevens ontvangen

Activity diagram


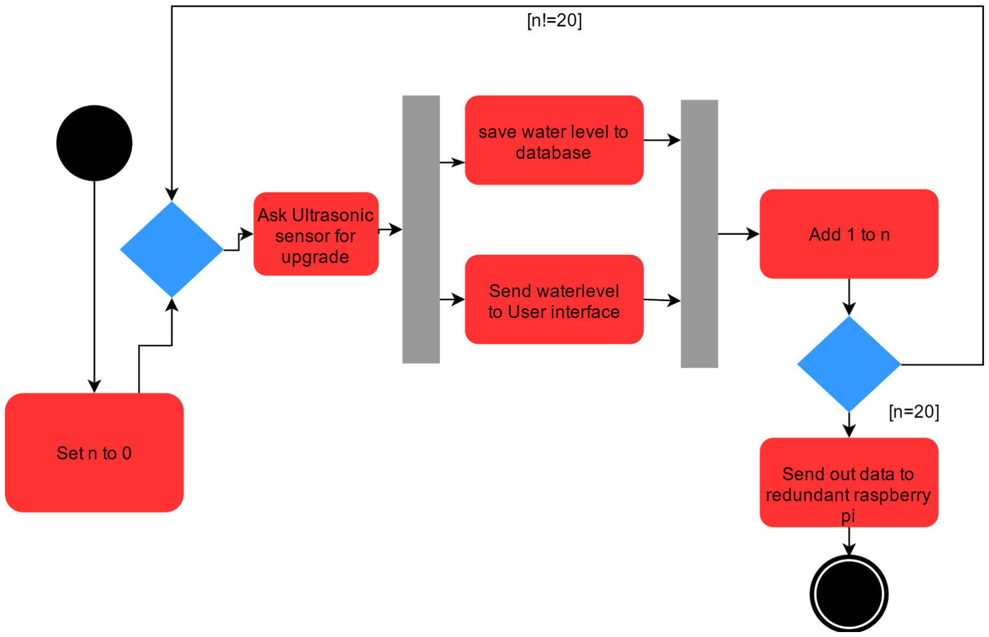
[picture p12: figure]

## Bronvermelding

Inspectie waterkeringen. (2014, april). Beheer- en onderhoudsplan waterkeringen.
Geraadpleegd van
http://www.inspectiewaterkeringen.nl/media/inspectiewaterkeringen/org/documents/producten/zorgplichtvoorbeelden/beheer-%20en%20onderhoudsplan%20waterkeringen%202014-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 s%20aa%20en%20maas.pdf (http://www.inspectiewaterkeringen.nl/media/inspectiewaterkeringen/org/documents/producten/zorgplichtvoorbeelden/beheer-%20en%20onderhoudsplan%20waterkeringen%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)

Rijkswaterstaat. (2012, 07 juni). Onze waterkeringen.
Geraadpleegd van
https://staticresources.rijkswaterstaat.nl/binaries/Factsheet%20onze%20waterkeringen_tcm21-7 0612.pdf (https://staticresources.rijkswaterstaat.nl/binaries/Factsheet%20onze%20waterkeringen_tcm21-70612.pdf)

Rijkswaterstaat. (z.j.). Maeslantkering.
Geraadpleegd van
http://www.rijkswaterstaat.nl/water/waterbeheer/bescherming-tegen-het-water/waterkeringen/deltawerken/maeslantkering.aspx (http://www.rijkswaterstaat.nl/water/waterbeheer/bescherming-tegen-het-water/waterkeringen/deltawerken/maeslantkering.aspx)

Helpdesk water. (2017). Software wettelijk beoordelingsinstrumentarium.
Geraadpleegd van
https://www.helpdeskwater.nl/publish/pages/36814/factsheet_software_wettelijk_beoordelingsinstrumentarium_2017.pdf (https://www.helpdeskwater.nl/publish/pages/36814/factsheet_software_wettelijk_beoordelingsinstrumentarium_2017.pdf)

Ricardo van Rijkswaterstaat (2016, 25 januari) 0800-8002

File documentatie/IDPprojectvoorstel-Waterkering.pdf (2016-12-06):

# IDP projectvoorstel - Waterkering

Versie 1.0.

## Afspraken

1. We hebben met de groep afgesproken dat we in plaats van Trello, Asana zullen gebruiken.
2. Indien afspraken niet op tijd af kunnen zijn, moet dit tijdig aangegeven worden via WhatsApp. Dit moet dan in overleg met de planner en de rest van de groep. Daarna worden deze wijzigingen doorgevoerd in Asana.
3. Twee keer per week een korte meeting met iedereen.
4. Hou elkaar op de hoogte, vertel wat je doet en wat er niet lukt. Binnen de meetings kunnen we bespreken hoe we dit kunnen oplossen.
5. Versiebeheer van de applicatie wordt beheerd in Github. Voordat je begint met het werken aan de applicatie moet je eerst syncen.
6. Bij vaker overtreden van bovenstaande afspraken, wordt in overleg met elkaar besproken wat de consequenties inhouden.

## Rolverdeling

Teamleider: Vince van Noort Planner: Bart Hiemstra
Notulist: Sijmen Jaarsma
Voorzitter: Jeroen van der Burgt Documentatie: Jody Schuller

## Context

De Maeslantkering bestaat uit twee grote sluisdeuren, aangestuurd door een systeem dat op basis van weersinformatie beslissingen maakt. Nadat de sluisdeuren zijn gesloten door het systeem, kan een persoon niet beïnvloeden of de deur weer opengaat. Dit kan alleen worden gedaan door het systeem zelf wanneer de weersinformatie dit toelaat.

## Kwestie en aanleiding

Ons team wil ervoor zorgen dat een systeem als de Maeslantkering open source te bekijken wordt. Waardoor andere mensen op de wereld van dit systeem kunnen leren. Er is al meerdere malen aangetoond dat dit belangrijk is en zorgt voor snelle groei binnen softwaresystemen. Hier willen wij aan bijdragen.

## Bedoeling & Resultaat

Aan het eind van het project moet een proof of concept worden gepresenteerd van onze eigen versie van de Maeslantkering. Dit hoeft alleen op basis van de waterstanden en niet van de overige weergegevens. Het is de bedoeling dat er een duidelijk advies wordt uitgebracht, een werkend prototype en een bugvrije tekst.

## Beoogde aanpak

Om dit resultaat te willen bereiken zal een hechte samenwerking vereist zijn. Dit willen we zelf doen via Asana in plaats van trello en door wekelijks 2 meetings met het hele team in te plannen. Vince zal iedereen proberen aan te sturen en Bart zal de planning in de gaten houden. Jeroen zal tijdens de meetings ervoor zorgen dat iedereen duidelijk krijgt wat hij wil vertellen. Sijmen zorgt ervoor dat dit allemaal duidelijk op papier komt te staan. En jody documenteert wat er in onze applicatie verandert tijdens de weg naar het proof of concept.

## Taakverdeling

Business IT & Management (Jody Schuller)
Maak een overzicht van de betrokken instanties en geef de verantwoordelijkheden van elke instantie weer. Ontwerp en beschrijf de procedures voor deze instanties, rekening houdend met de uiteindelijke werking van jullie uitwerking van de Maeslantkering. De BIM rol geeft intern ook advies over de aansluiting van techniek en organisatie.

Software & Information Engineering (Bart Hiemstra & Sijmen Jaarsma)
Ontwerp en implementeer een informatiesysteem dat met de gegeven informatie van de sensoren het weermodel beschrijft en weergeeft op het scherm. Bij extreem weer moet de sluis worden gesloten. De informatie die nodig is voor het weermodel komt via het netwerk van de verschillende sensoren. De precieze beschrijving van deze informatie is te vinden in de bijbehorende documentatie (zie bronnen).

System and Network Engineering (Jeroen van der Burgt)
Ontwerp en implementeer (virtueel) de infrastructuur die nodig is voor de werking van de Maeslantkering. Er zijn twee (redundante) stations waar de beslissing van het weer en de beslissing om de sluis open en dicht te doen wordt genomen. Beide stations beoordelen onafhankelijk van elkaar, maar op basis van dezelfde gegevens en hetzelfde model. Op elk willekeurig moment is één van de twee stations primary en de andere secondary. Als de primary uitvalt, neemt het secondary station het over.

Technische Informatica (Vince van Noort)
Ontwerp en implementeer (minimaal een van) de sensoren die gebruikt worden voor het weermodel en de aansturing van de sluisdeuren. De gegevens van de sensor moeten worden uitgelezen en doorgegeven via het netwerk. Bij een beslissing om de sluisdeuren te sluiten of openen, moeten de motoren die de sluisdeuren sluiten en openen worden aangestuurd.

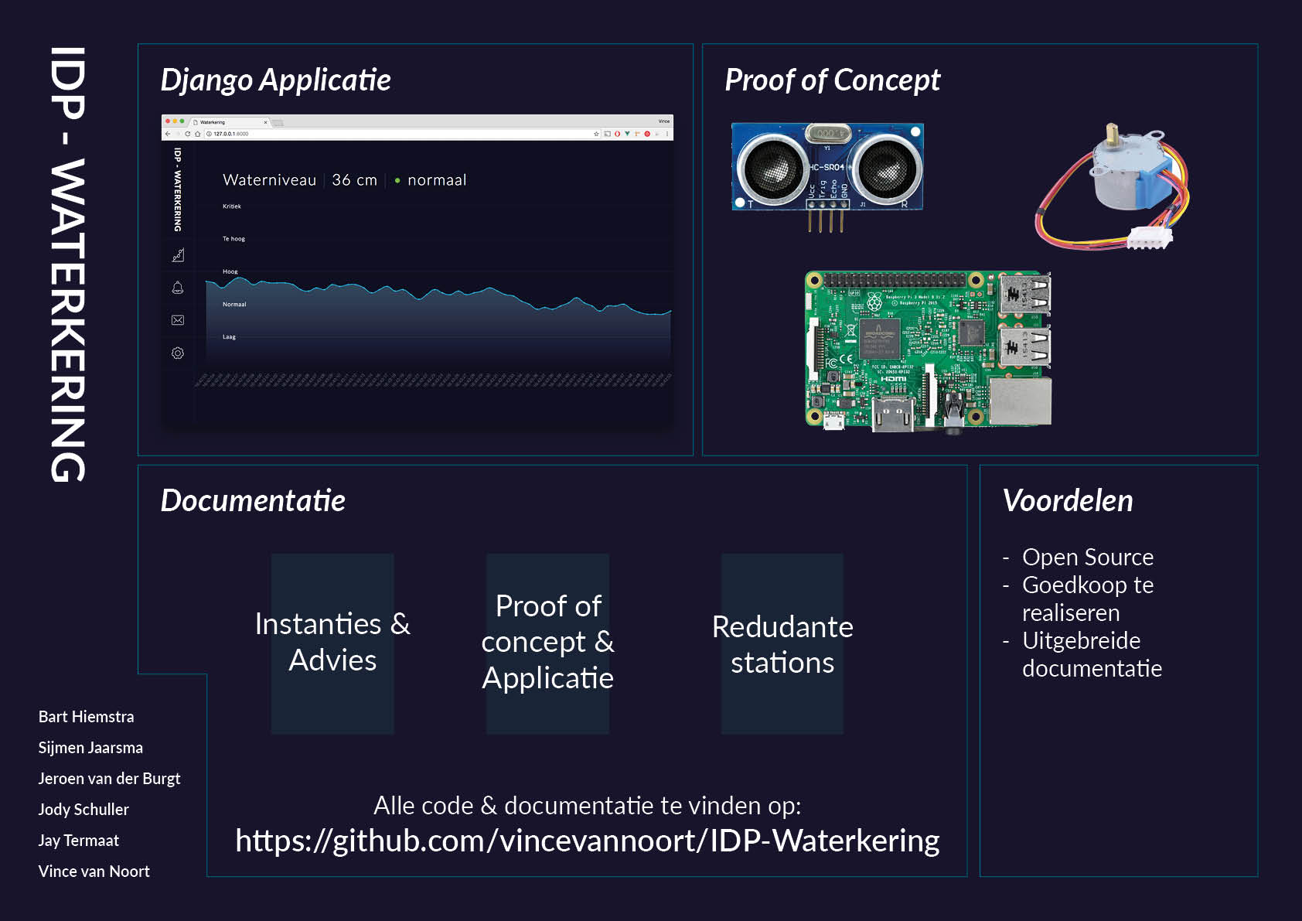
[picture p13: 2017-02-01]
ontwerp/presentatie-poster.jpg

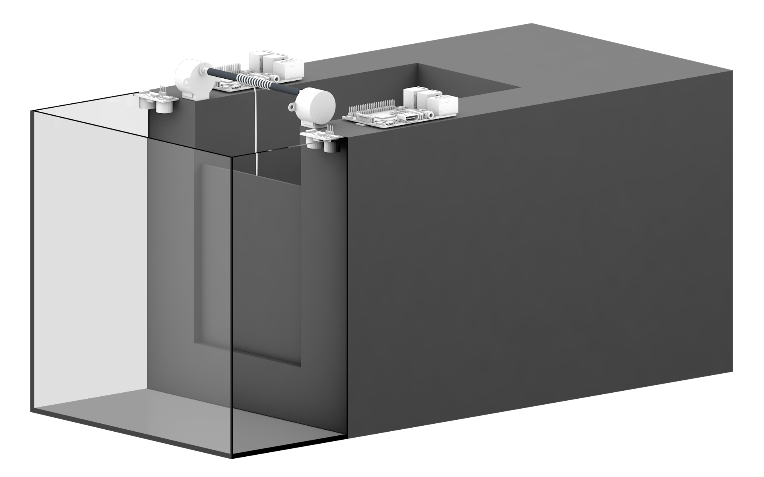
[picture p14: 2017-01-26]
ontwerp/render/render.png

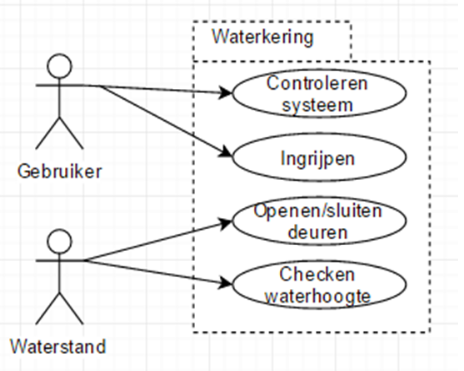
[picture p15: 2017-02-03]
documentatie/modellen/Use case.png

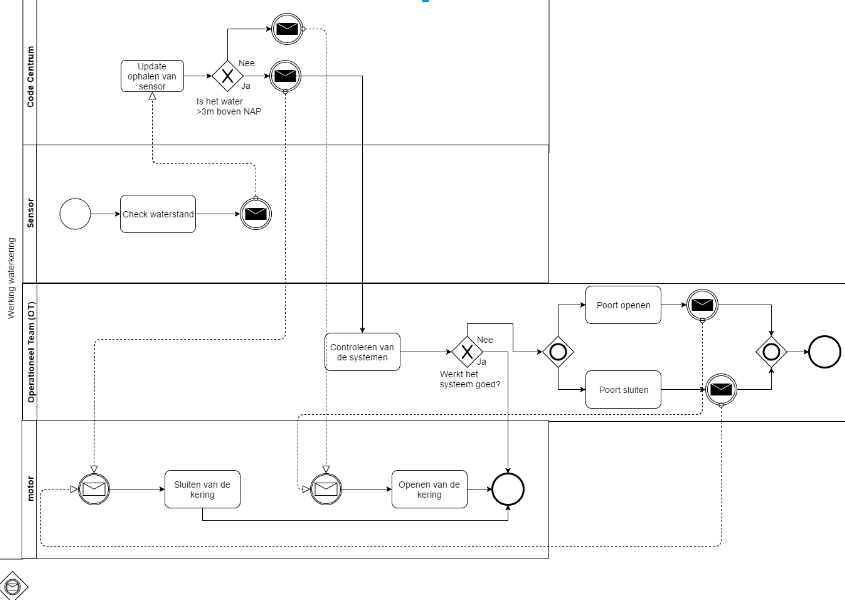
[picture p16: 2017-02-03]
documentatie/modellen/RDBM model.png

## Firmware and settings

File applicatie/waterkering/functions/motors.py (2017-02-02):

# credits to https://github.com/recantha/stepper-pi
import applicatie.settings as settings
from waterkering.models import Melding
import time

# GPIO variables
if settings.RASPBERRY == True: 
    import RPi.GPIO as GPIO
    GPIO.setmode(GPIO.BOARD)

    for pins in settings.MOTOR_PINS:
        for pin in pins:
            GPIO.setup(pin, GPIO.OUT)
            GPIO.output(pin, 0)

    # motor 1
    P1 = settings.MOTOR_PINS[0][0]
    P2 = settings.MOTOR_PINS[0][1]
    P3 = settings.MOTOR_PINS[0][2]
    P4 = settings.MOTOR_PINS[0][3]

    # motor 2
    P5 = settings.MOTOR_PINS[1][0]
    P6 = settings.MOTOR_PINS[1][1]
    P7 = settings.MOTOR_PINS[1][2]
    P8 = settings.MOTOR_PINS[1][3]

    # variables for calculations
    deg_per_step = 5.625 / 64 
    steps_per_rev = int(360 / deg_per_step)
    step_angle = 0
    revs_per_minute = 15
    _rpm = revs_per_minute

    # T is the amount of time to stop between signals
    _T = (60.0 / _rpm) / steps_per_rev


class Motor:

    def close_gate(angle=settings.TURN_ANGLE):

        # Only allow to close doors when current status is opened
        if settings.status == 'opened':

            # Set status to closing
            print('Closing gate.')
            settings.status = 'closing'
            Melding(melding = 'Closing').save()

            # Raspberry Pi connected
            if settings.RASPBERRY == True:
                target_step_angle = (int(angle / deg_per_step) / 8)
                steps = target_step_angle
                steps = int(steps % steps_per_rev)
                GPIO.output(P1, 0)
                GPIO.output(P5, 0)
                GPIO.output(P2, 0)
                GPIO.output(P6, 0)
                GPIO.output(P3, 0)
                GPIO.output(P7, 0)
                GPIO.output(P4, 0)
                GPIO.output(P8, 0)

                for i in range(steps):
                    GPIO.output(P3, 0)
                    GPIO.output(P7, 0)
                    time.sleep(_T)
                    GPIO.output(P1, 1)
                    GPIO.output(P5, 1)
                    time.sleep(_T)
                    GPIO.output(P4, 0)
                    GPIO.output(P8, 0)
                    time.sleep(_T)
                    GPIO.output(P2, 1)
                    GPIO.output(P6, 1)
                    time.sleep(_T)
                    GPIO.output(P1, 0)
                    GPIO.output(P5, 0)
                    time.sleep(_T)
                    GPIO.output(P3, 1)
                    GPIO.output(P7, 1)
                    time.sleep(_T)
                    GPIO.output(P2, 0)
                    GPIO.output(P6, 0)
                    time.sleep(_T)
                    GPIO.output(P4, 1)
                    GPIO.output(P8, 1)
                    time.sleep(_T)

            # Change status to closed regardless whether the RPi is connected and logs the action
            settings.status = 'closed'
            Melding(melding = 'Closed').save()

        # Fires when the close_gate function in called but the current status is not opened
        else:
            print('The gates cannot be closed when the gates are not open.')
            Melding(melding = 'Tried closing but failed because doors where not open').save()


    def open_gate(angle=settings.TURN_ANGLE):

        # Only allow to open doors when current status is closed
        if settings.status == 'closed':

            # Set status to opening
            print('Opening gate.')
            settings.status = 'opening'
            Melding(melding = 'Opening').save()

            # Raspberry Pi connected
            if settings.RASPBERRY == True:
                target_step_angle = (int(angle / deg_per_step) / 8)
                steps = target_step_angle
                steps = int(steps % steps_per_rev)
                GPIO.output(P1, 0)
                GPIO.output(P5, 0)
                GPIO.output(P2, 0)
                GPIO.output(P6, 0)
                GPIO.output(P3, 0)
                GPIO.output(P7, 0)
                GPIO.output(P4, 0)
                GPIO.output(P8, 0)

                for i in range(steps):
                    GPIO.output(P4, 1)
                    GPIO.output(P8, 1)
                    time.sleep(_T)
                    GPIO.output(P2, 0)
                    GPIO.output(P6, 0)
                    time.sleep(_T)
                    GPIO.output(P3, 1)
                    GPIO.output(P7, 1)
                    time.sleep(_T)
                    GPIO.output(P1, 0)
                    GPIO.output(P5, 0)
                    time.sleep(_T)
                    GPIO.output(P2, 1)
                    GPIO.output(P6, 1)
                    time.sleep(_T)
                    GPIO.output(P4, 0)
                    GPIO.output(P8, 0)
                    time.sleep(_T)
                    GPIO.output(P1, 1)
                    GPIO.output(P5, 1)
                    time.sleep(_T)
                    GPIO.output(P3, 0)
                    GPIO.output(P7, 0)
                    time.sleep(_T)

            # Change status to opened regardless whether the RPi is connected and logs the action
            settings.status = 'opened'
            Melding(melding = 'Opened').save()

        # Fires when the open_gate function in called but the current status is not closed
        else:
            print('The gates cannot be opened when the gates are not closed.')
            Melding(melding = 'Tried opening but failed because doors where not closed').save()

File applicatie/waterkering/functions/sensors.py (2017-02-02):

import applicatie.settings as settings
import time
from random import randrange
from waterkering.models import Waterstand

# GPIO variables
if settings.RASPBERRY == True: 
    print('initialize sensor')
    import RPi.GPIO as GPIO

    # sensor 1
    GPIO.setmode(GPIO.BOARD)
    GPIO_TRIGGER = settings.SENSOR_PINS[0];
    GPIO_ECHO = settings.SENSOR_PINS[1];
    GPIO.setup(GPIO_TRIGGER, GPIO.OUT)
    GPIO.setup(GPIO_ECHO, GPIO.IN)
    GPIO.output(GPIO_TRIGGER, False)

class Sensor:
    def get_sensor_waterstand(previousWaterstand):
        
        # Raspberry Pi connected
        if settings.RASPBERRY == True:
            def measure_waterstand():
                # activate GPIO sensors
                GPIO.output(GPIO_TRIGGER, True)
                time.sleep(0.00001)
                GPIO.output(GPIO_TRIGGER, False)

                # check distance with ultrasonic waves
                start = time.time()
                while GPIO.input(GPIO_ECHO) == 0:
                    start = time.time()
                while GPIO.input(GPIO_ECHO) == 1:
                    stop = time.time()

                # compute elapsed time based on waves
                elapsed = stop-start
                distance = (elapsed * 34300) / 2

                # check if waterlevel exceeds max height
                if distance >= settings.WATER_HEIGHT_IN_CM: 
                    distance = 99

                actual_distance = round(settings.WATER_HEIGHT_IN_CM - distance, 2)
                print(actual_distance)
                return actual_distance
                
            return measure_waterstand()

        # Raspberry Pi not connected, returning random value for testing purposes
        else:
            distance = int(previousWaterstand) + randrange(-3, 3 + 1)
            if distance >= 100: distance = 99
            elif distance <= 0: distance = 1
            return distance

    def save_sensor_waterstand(value):
        Waterstand(waterstand = value).save()

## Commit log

2017-01-23 Start threading
2017-01-24 Change location of main thread
2017-01-24 Raspberry Global Variable & Sensors update
2017-01-24 Threading start
2017-01-24 Update Sensors
2017-01-24 Update sensors with less random data
2017-01-24 Thread for updating on serverside instead on client side
2017-01-26 model for sensor reading
    blarbl
2017-01-26 Make Sensors a Class
2017-01-26 Remade and renamed exsisting model/added motor control model
2017-01-27 Motors implemented & updated settings
2017-01-27 Change stemmed to board instead of bcd
2017-01-27 Change numbers of motors
2017-01-30 Change motor.py so order of pins is more logical
2017-01-30 Revert "Change motor.py so order of pins is more logical"
    This reverts commit c72d49c5d3a255fa941b598462d7eefeee3a0697.
    [motors.py]
2017-01-31 Technisch model & ontwerp
    [technisch_model.fzz]
2017-02-01 Presentatie modellen
    [technisch_model.fzz]
2017-02-01 Copy thread for Redundantie (Jeroen, Sijmen en Vince)
2017-02-02 Update controller and views so saving waterstand do not interrupt the saving process of the database
2017-02-02 Measure Waterlevel instead of the distance from sensor
2017-02-02 Update model
    [technisch_model.fzz]
